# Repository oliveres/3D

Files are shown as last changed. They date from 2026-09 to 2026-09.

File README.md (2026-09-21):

# 3D models & browser tools

3D-printable models, editable CAD sources and browser configurators.

**[Open the tools website](https://oliveres.github.io/3D/)**

## Projects

| Project | Browser tool | Files and guide |
|---|---|---|
| DIN rail distribution stud — M6 / M8 / M10 | [Open configurator](https://oliveres.github.io/3D/din-rail/) | [Project folder](din-rail/) |
| DIN rail MEGA fuse holder — 2 × M8, 50.8 mm pitch | [Open configurator](https://oliveres.github.io/3D/mega-fuse/) | [Project folder](mega-fuse/) |

The DIN rail project provides a common-potential connection point for cable lugs, for example in Victron Energy systems. The separate MEGA fuse project mounts a fuse vertically across the rail on a compact 27 mm carrier. Both packages include printable STL files, STEP models, an OpenSCAD source, a Bambu Studio project and printing instructions.

Both projects use extended retaining lips and a U spring with 1.40 mm walls. The spring is thickened outwards by 0.20 mm, and its release-notch shoulder is removed. The inner spring opening, retaining-tip gap, rail registration faces and fuse carrier remain unchanged by this spring update.

## One Pages site, multiple tools

GitHub Pages publishes the root of the `main` branch. `.nojekyll` keeps the site as plain static files; no build system is needed.

Every tool has its own folder and `index.html`:

```text
index.html                  → https://oliveres.github.io/3D/
din-rail/index.html         → https://oliveres.github.io/3D/din-rail/
mega-fuse/index.html        → https://oliveres.github.io/3D/mega-fuse/
```

To add another tool:

1. Create a folder such as `your-next-tool/` with an `index.html` and any required assets.
2. Use relative links for local assets and downloads, so the tool works under `/3D/`.
3. Add a link or card to the root `index.html` and a row to the project table above.
4. Commit and push to `main`. GitHub Pages publishes the updated site automatically.

The new folder URL works once deployment finishes; the card on the home page is added manually. Files with other names also work at their full path, such as `your-next-tool/configurator.html`.

See [GitHub's Pages publishing documentation](https://docs.github.com/en/pages/getting-started-with-github-pages/configuring-a-publishing-source-for-your-github-pages-site).

## Credits and licensing

See each project's credits and any licence supplied with it. See the [distribution stud credits](din-rail/CREDITS.md) and [MEGA fuse holder credits](mega-fuse/CREDITS.md). No distribution licence for these new projects has been selected yet; credits to reference designs are included.

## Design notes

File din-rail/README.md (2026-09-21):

# DIN Rail Distribution Stud Holder

This is a **distribution stud for cable lugs**: a common-potential connection point for joining incoming and outgoing cables and distributing power, for example in **Victron Energy systems**. Cable lugs are stacked on the metal bolt and clamped with a nut. The printed holder secures that stud to the DIN rail.

A one-piece holder that clips onto a nominal 35 mm DIN rail and holds a hex-head bolt perpendicular to the rail. The head inserts from the rear into a captive hex recess; the threaded shank points outwards. One rail hook is fixed and the opposite latch uses a U-shaped spring with a screwdriver release notch.

[Open the live configurator](https://oliveres.github.io/3D/din-rail/) · [Download the complete offline package](DIN_Rail_Bolt_Holder_MakerWorld_Package.zip)

## Quick start

Open **index.html** in a desktop browser. It works offline and needs no installation. Select the four settings, preview the part and download an STL.

Alternatively, choose an STL from the `STL` folder, or open **DIN_Rail_Bolt_Holder.scad** in OpenSCAD, use its Customizer, press **F6**, then **File → Export → Export as STL**.

For Bambu Studio, `BambuStudio/DIN_M8_2module_36mm_X1C_PLA.3mf` contains the default M8 holder and suggested X1 Carbon / 0.4 mm nozzle / Generic PLA settings. Check the selected printer, filament and build plate before slicing. The editable project includes a sliced preview. Select your own printer, material and plate settings and slice again before printing.

## Four settings

| Setting | Choices / range | Default |
|---|---|---|
| Hex-head bolt | M6, M8, M10 with 16 mm head, M10 with 17 mm head | M8, 13 mm head |
| Holder width | M6/M8: 18 or 36 mm; M10: 27 or 36 mm | 36 mm |
| Rail width allowance | −0.50 to +0.50 mm relative to the 35.75 mm stop spacing | 0.00 mm |
| DIN rail sheet thickness | 0.80 to 2.00 mm | 1.00 mm |

One module is defined as **18 mm** in this model. The 27 mm option is 1.5 modules. The browser offers only compatible widths; OpenSCAD rejects invalid combinations.

### Default dimensions

- Nominal DIN rail width: **35 mm**.
- Distance between the rail registration faces: **35.75 mm**.
- U spring wall: **1.40 mm**; outer radius: **3.00 mm**.
- Distance between the retaining tips: **31.80 mm** (each lip extended inward by 0.50 mm).
- Rail sheet thickness: **1.00 mm**; both flange grooves: **1.20 mm**.
- Clearance between the body support and spring latch: **0.40 mm**, maintained across the sheet-thickness range.
- M8 holder width along the rail: **36 mm**.
- Default overall mounted envelope: **36 × 50 × 14.2 mm**.
- M8 through-hole: **8.60 mm**; hex recess: **13.35 mm across flats**, **6.80 mm deep**.

The width allowance changes the total stop spacing, split equally between both ends. For example, **+0.10 mm** gives **35.85 mm** stop spacing; each end moves outwards by 0.05 mm. A negative value narrows the gap. This is an adjustment to the model, not a measurement of the rail itself.

| Bolt | Head across flats | Through-hole | Hex recess across flats | Recess depth |
|---|---:|---:|---:|---:|
| M6 | 10 mm | 6.60 mm | 10.35 mm | 5.50 mm |
| M8 | 13 mm | 8.60 mm | 13.35 mm | 6.80 mm |
| M10 ISO | 16 mm | 10.60 mm | 16.35 mm | 8.00 mm |
| M10 DIN | 17 mm | 10.60 mm | 17.35 mm | 8.00 mm |

All eight supplied STL/STEP variants use **0.00 mm allowance** and **1.00 mm sheet thickness**. Bolt length is left to the application. Bolts, washers, nuts and DIN rail are not included.

## Printing

The STL exports are already lying on their side. Keep this orientation: it places spring bending in the layer plane. The STEP models use the mounted coordinate system and must be oriented before printing.

Suggested starting settings, also included in the Bambu Studio project:

- 0.4 mm nozzle, 0.20 mm layer height.
- Arachne wall generator, 6 walls, 6 top and bottom layers.
- 60% gyroid infill.
- Supports off; optional 4 mm outer brim.
- Remove any brim strands from the spring gap before fitting.

The clip design was developed through physical fit trials in PLA. The modular widths and custom parameter combinations need their own fit check; holder width and material affect spring stiffness. PLA, PETG and ASA require material-specific printing settings. The included project uses Generic PLA.

## Assembly and release

1. Clear the through-hole, hex recess and spring gap of stray filament.
2. Insert the bolt from the rear until its head sits in the hex recess.
3. Hook the fixed side over one DIN rail flange, then press the spring side over the opposite flange.
4. Place the cable lugs for the same electrical potential onto the exposed bolt and secure the connection with the appropriate nut and washers.
5. To remove the holder, use the notch beside the moving jaw to gently deflect the latch away from the rail, then lift that side free.

This is a mechanical holder. It does not establish an electrical current rating or a certified insulation rating for a cable connection.

## Package contents

- `index.html` — self-contained English browser configurator and STL exporter.
- `DIN_Rail_Bolt_Holder.scad` — self-contained English OpenSCAD source with four Customizer inputs.
- `STL/` — eight ready-to-slice variants, in print orientation.
- `STEP/` — matching eight solid CAD models, in mounted orientation.
- `BambuStudio/` — default M8 / 36 mm editable project with suggested settings.
- `images/` — two labelled CAD renders and a dimension diagram.
- `publishing/` — English MakerWorld listing text and upload notes for the author.
- `CREDITS.md` — design inspiration and dimensional references.
- `variants.json` — dimensions and parameters of each supplied variant.
- `CHECKSUMS.sha256` — file integrity hashes.

Digital validation covered 72 parameter combinations and comparison of 16 OpenSCAD/browser export pairs. All those meshes are closed, single solids. The support-to-latch gap was checked in every export. This does not replace a physical fit or load test of a chosen variant.

## Retention update

Both retaining lips were extended 0.50 mm towards the centre, including their insertion chamfers. This reduces the tip gap by 1.00 mm while preserving the rail registration faces, groove thickness, spring profile and bolt pocket. At +0.05 mm rail allowance, the tip gap is 31.85 mm; at the default 0.00 mm allowance it is 31.80 mm. The longer lips address reported accidental release; this revision still needs its own physical fit check.

## Spring update

The U spring is thickened by 0.20 mm along its outside, increasing its nominal wall from 1.20 to 1.40 mm. The moving leg and release-notch wall meet without the former 0.10 mm shoulder. The inside of the U, retaining tips, rail fit and bolt recess stay unchanged. This adjustment follows print feedback that the previous spring released too easily; fitting and release force still need to be checked on the actual print.

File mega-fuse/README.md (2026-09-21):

# DIN rail MEGA fuse holder

A compact, two-part holder for mounting a MEGA fuse vertically across a 35 mm DIN rail, for example in Victron Energy systems. Two M8 bolts have a fixed 50.8 mm centre spacing. Cable lugs attach at the two separate fuse terminals.

The current package combines **DIN clip v5** with the accepted **fuse carrier v3**. The U spring is thickened by 0.20 mm on the outside, increasing its nominal wall from 1.20 to 1.40 mm and removing the small shoulder at the release notch. The previously extended retaining tips remain unchanged. The carrier is unchanged. One hook stays fixed and the opposite hook releases through a U-shaped spring and screwdriver notch.

[Open the live configurator](https://oliveres.github.io/3D/mega-fuse/) · [Download the complete offline package](MEGA_Fuse_Holder_Package.zip)

## Quick start

Open `index.html` in a browser to preview the assembly, inspect the profile or exploded view, adjust rail fit and download STL files. Everything works offline. The package also includes editable OpenSCAD and STEP models and a Bambu Studio project.

## Dimensions

| Feature | Default |
|---|---:|
| Width along rail | 27 mm / 1.5 modules |
| Height across rail | 72.8 mm |
| Assembly depth, excluding hardware | 25.2 mm |
| M8 bolt pitch | 50.8 mm |
| M8 clearance holes | 8.6 mm |
| M8 hex-head pockets | 13.35 mm across flats × 6.3 mm deep |
| Matching clip/carrier contact footprint | 27 × 22 mm |
| Central recess below the terminal pads | 7.4 mm |
| Minimum free depth over the 29.2 × 19 mm fuse footprint, including chamfers | 6.1 mm |
| Rail registration spacing | 35.75 mm |
| Gap between retaining tips | 31.80 mm |
| Rail sheet thickness / flange grooves | 1.00 / 1.20 mm |
| Support-to-latch gap | 0.40 mm |
| U spring wall / outer radius | 1.40 / 3.00 mm |
| Static clearance above the spring arch | 0.80 mm |

The fuse footprint follows the supplied drawing: 68.8 mm overall length, 50.8 mm hole pitch, 8.7 mm holes, a 29.2 × 19 mm central body and 16.2 mm wide terminals. The drawing did not specify the side profile; check the actual body underside against the recess.

## Hardware and assembly

- Two M8 hex-head bolts with 13 mm heads; choose their length for the fuse and terminal stack.
- Two **M4 × 8 DIN 912 socket-head screws** and two plain M4 nuts, 7 mm across flats and nominally 3.2 mm thick.
- Suitable M8 nuts and washers for the actual terminal stack.

1. Insert the M8 bolts into the carrier from the rear, with their threads pointing outwards.
2. Insert the two M4 nuts into the rear pockets of the DIN clip.
3. Join the parts with the two M4 × 8 screws inserted through the central front recess. Their heads sit below its floor. Longer screws can protrude towards the rail.
4. Engage the fixed hook, then press the spring side onto the DIN rail. For removal, use the notch to move the spring latch outwards.
5. Mount the fuse and cable lugs with metal-to-metal contact. The two terminals remain separate except through the fuse.

This is a mechanical holder. It does not establish a current, thermal, fastening-torque or certified insulation rating for an electrical installation.

## Printing and rail fit

Both STL files are already oriented on their side, with a print height of 27 mm, so spring bending stays in the layer plane. Suggested starting settings are a 0.4 mm nozzle, 0.2 mm layers, Arachne, 6 walls, 60% gyroid infill and supports off. Clear any brim strands from the spring gap. The included Bambu project uses X1 Carbon and Generic PLA settings; select your actual printer, material and build plate, then slice again before printing. The project includes a sliced preview.

Rail allowance ranges from −0.50 to +0.50 mm. It changes the registration spacing of 35.75 mm and the retaining-tip gap of 31.80 mm by the same amount, shared equally between both ends. **At +0.05 mm allowance, the tip gap is 31.85 mm.** Sheet thickness ranges from 0.80 to 2.00 mm; each groove adds 0.20 mm clearance. The M8 pitch and carrier stay fixed.

The previous clip and carrier were refined from user feedback. The thicker spring is a new retention change and needs a fit check on the actual rail; narrower/wider allowances and material changes affect fitting and release force.

## Files

- `STL/MEGA_M8_clip_27mm_v5.stl` — current DIN clip with a thicker U spring and extended lips.
- `STL/MEGA_M8_carrier_27mm_v3.stl` — unchanged fuse carrier; an existing v3 print can be reused.
- `STEP/` — both parts and their assembly in installed coordinates.
- `MEGA_Fuse_Holder.scad` — both parts with rail allowance and sheet-thickness parameters; select `clip`, `carrier`, `layout` or `assembly`, render with F6, then export STL.
- `BambuStudio/` — current two-part X1 Carbon project, prepared on its side.
- `images/` — current CAD renders and dimensioned profile.
- `dimensions.json`, `CHECKSUMS.sha256` — dimensions and file integrity hashes.
- `publishing/`, `CREDITS.md` — listing text and references.

Product names identify compatibility; this is an independent design without a Victron Energy endorsement.

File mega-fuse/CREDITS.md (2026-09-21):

# Credits and references

This MEGA fuse holder and its two-parameter rail-fit configurator were constructed for this project. No reference STL is distributed in this package. The spring-clip mechanism was inspired by these models:

- **DIN Rail Clip (side mount)** — Catatat / PlasticXYZ. https://www.printables.com/model/1753870-din-rail-clip-side-mount
- **Adjustable DIN Rail Clip (FreeCAD)** — kc2zgu / marauder156. https://www.printables.com/model/556742-adjustable-din-rail-clip-freecad

The reference models were identified during development as CC BY 4.0. Preserve these credits and source links when publishing. See https://creativecommons.org/licenses/by/4.0/ for that reference licence. This statement credits the inspirations; it does not select a distribution licence for the new package.

The rail-clip profile comes from the preceding distribution-stud project, refined using physical print feedback. The carrier was accepted during user refinement; this release keeps it unchanged and thickens the outside of the U spring by 0.20 mm following further feedback about easy release. The thicker spring needs its own fit check. The assembly has two rear M8 head recesses at 50.8 mm pitch, a central body recess and two M4 attachment points. Rail width and sheet thickness are adjustable. CAD and configurator development used AI assistance.

Dimensional references:

- User-supplied MEGA fuse drawing: 50.8 mm pitch, 68.8 mm length, 29.2 × 19 mm central body footprint, 16.2 mm tabs and 8.7 mm holes.
- Victron fuse datasheet: https://www.victronenergy.com/upload/documents/Datasheet-Midi,-Mega-and-ANL-fuses,-and-fuse-holders-EN-.pdf

- Böllhoff DIN 933 hex-head screw dimensions: https://uk.misumi-ec.com/pdf/ds/AAU1/AAU1_DIN_933_Stahl_8_8_data_sheet_en1.pdf
- Würth, DIN / ISO hex-head differences: https://www.wuerth.de/web/de/awkg/kompetenz/din_iso_normteile/din-933-931-iso-4014-4017-sechskantschrauben.php/1000
- Schneider Electric, 18 mm module convention: https://www.se.com/in/en/faqs/FA600017/

Product names are used to identify compatibility or tooling, without an endorsement claim.

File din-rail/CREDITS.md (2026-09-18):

# Credits and references

The holder geometry and its four-parameter configurator were constructed for this project. No reference STL is distributed in this package. The spring-clip mechanism was inspired by these models:

- **DIN Rail Clip (side mount)** — Catatat / PlasticXYZ. https://www.printables.com/model/1753870-din-rail-clip-side-mount
- **Adjustable DIN Rail Clip (FreeCAD)** — kc2zgu / marauder156. https://www.printables.com/model/556742-adjustable-din-rail-clip-freecad

The reference models were identified during development as CC BY 4.0. Preserve these credits and source links when publishing. See https://creativecommons.org/licenses/by/4.0/ for that reference licence. This statement credits the inspirations; it does not select a distribution licence for the new package.

The new geometry adds a rear captive hex-head recess, a perpendicular bolt hole, selectable modular widths, symmetric rail-width adjustment and sheet-thickness adjustment with a constant support-to-latch gap. The design was iteratively refined using physical print feedback. CAD and configurator development used AI assistance.

Dimensional references:

- Böllhoff DIN 933 hex-head screw dimensions: https://uk.misumi-ec.com/pdf/ds/AAU1/AAU1_DIN_933_Stahl_8_8_data_sheet_en1.pdf
- Würth, DIN / ISO hex-head differences: https://www.wuerth.de/web/de/awkg/kompetenz/din_iso_normteile/din-933-931-iso-4014-4017-sechskantschrauben.php/1000
- Schneider Electric, 18 mm module convention: https://www.se.com/in/en/faqs/FA600017/

Product names are used to identify compatibility or tooling, without an endorsement claim.

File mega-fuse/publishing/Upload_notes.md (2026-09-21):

# Publishing notes

Use the current package only: DIN clip v5 and fuse carrier v3. The carrier STL is byte-for-byte identical to the accepted v3 model. Clip v5 thickens the U spring by 0.20 mm on the outside (1.40 mm walls), removes the release-notch shoulder and preserves the previously extended retaining tips.

Include the two STLs, the Bambu project if desired, and the ZIP containing the offline configurator and editable sources. The images are CAD renders, not photographs of a print. Check the current hook fit before describing it as physically verified. Preserve CREDITS.md and choose the distribution licence explicitly when publishing; no licence for the new design has been selected here.

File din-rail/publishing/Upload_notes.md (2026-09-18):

# MakerWorld upload notes — for the author

Suggested title: **DIN Rail Distribution Stud for Cable Lugs | M6 / M8 / M10**

Suggested tags: DIN rail, TS35, distribution stud, cable lugs, common potential, power distribution, Victron Energy, M6, M8, M10, parametric, OpenSCAD, electrical cabinet.

## Files and description

1. Use the eight files in `STL/` as model variants. Each is a complete single part, already in print orientation.
2. Add the OpenSCAD file as the editable parametric source. The HTML configurator and other supporting files can be distributed in a ZIP of this package. Check the current upload form for accepted attachment formats.
3. Paste the text from `MakerWorld_description.md` into the model description.
4. Add the CAD renders and dimension diagram as supplementary illustrations. They are labelled as renders.
5. Select the distribution licence in the upload form and add the corresponding licence file to the package when chosen. No licence grant for this new work has been chosen on the author's behalf. Preserve the linked design credits.
6. Disclose the AI-assisted development where the upload form asks for it.

## Bambu Studio project and photographs

The project in `BambuStudio/` is the default M8 / 36 mm part with suggested X1 Carbon / 0.4 mm / Generic PLA settings. It has been checked by local slicing, but this exact width/profile has not been confirmed by a physical print in this package.

Before submitting it as a tested print profile, print that configuration and add an actual photograph of its result. Add a photo of the mounted holder as well if available. CAD renders do not demonstrate a successful physical print.

Bambu Lab's guidance on actual print photographs and profiles:

- https://blog.bambulab.com/makerworld-in-20-days/
- https://wiki.bambulab.com/en/makerworld/tutorials/print-profile-upload

This folder contains prepared upload materials. No MakerWorld listing has been created or published.

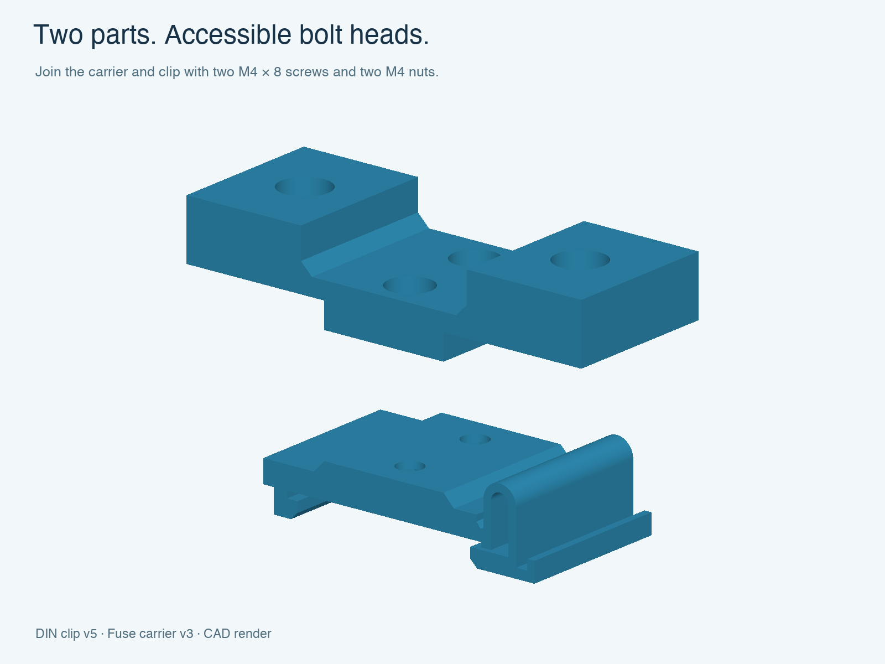
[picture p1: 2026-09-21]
mega-fuse/images/02_exploded.png

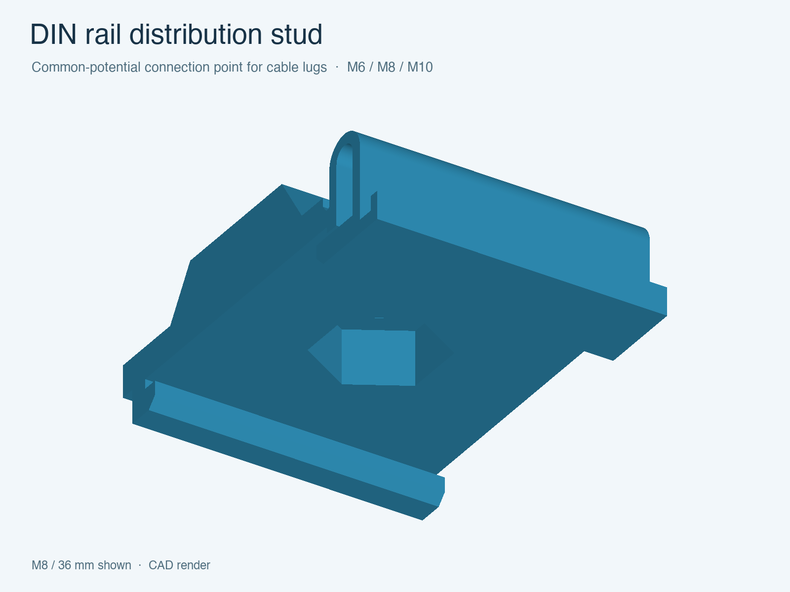
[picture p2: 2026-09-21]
din-rail/images/01_rear_CAD_render.png

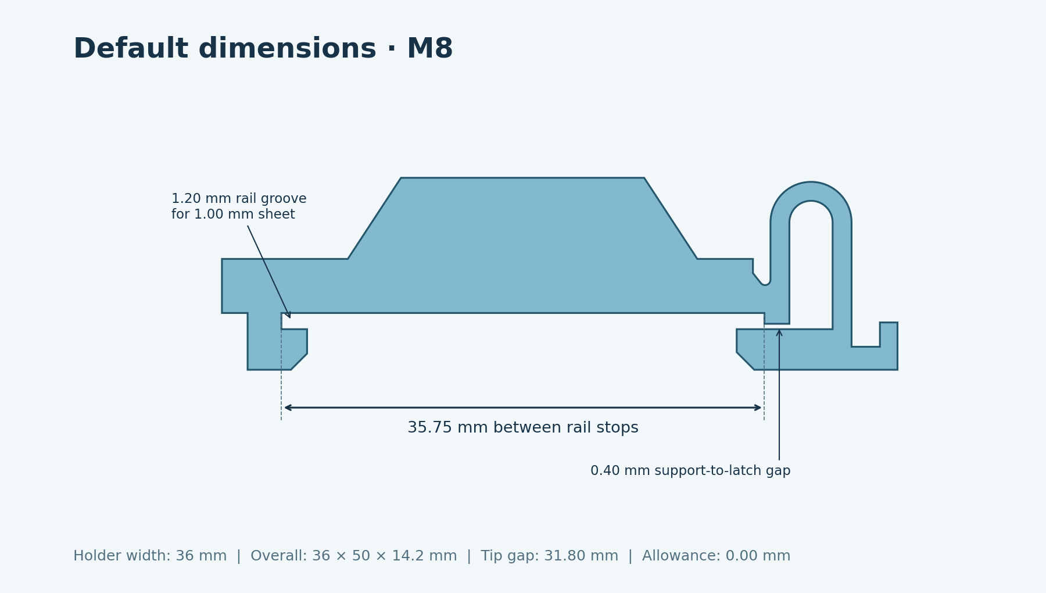
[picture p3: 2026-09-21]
din-rail/images/03_default_dimensions.png

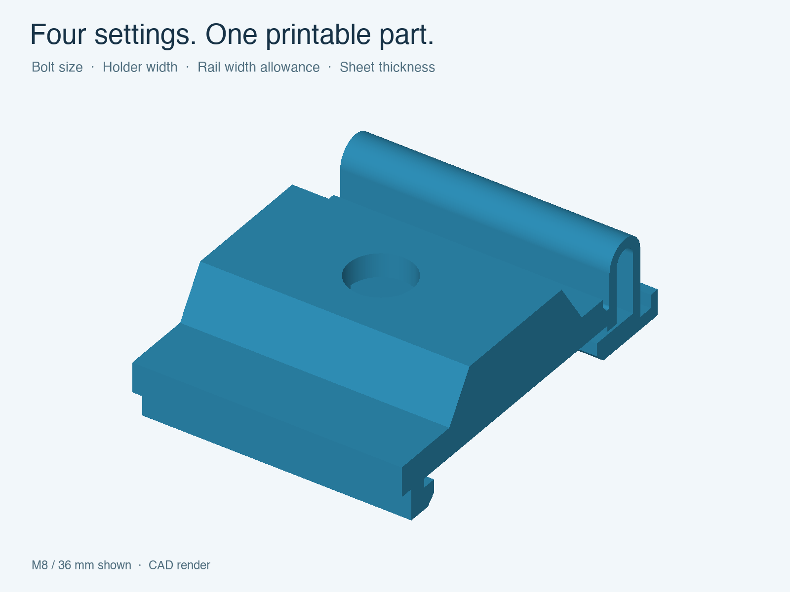
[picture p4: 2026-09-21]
din-rail/images/02_front_CAD_render.png

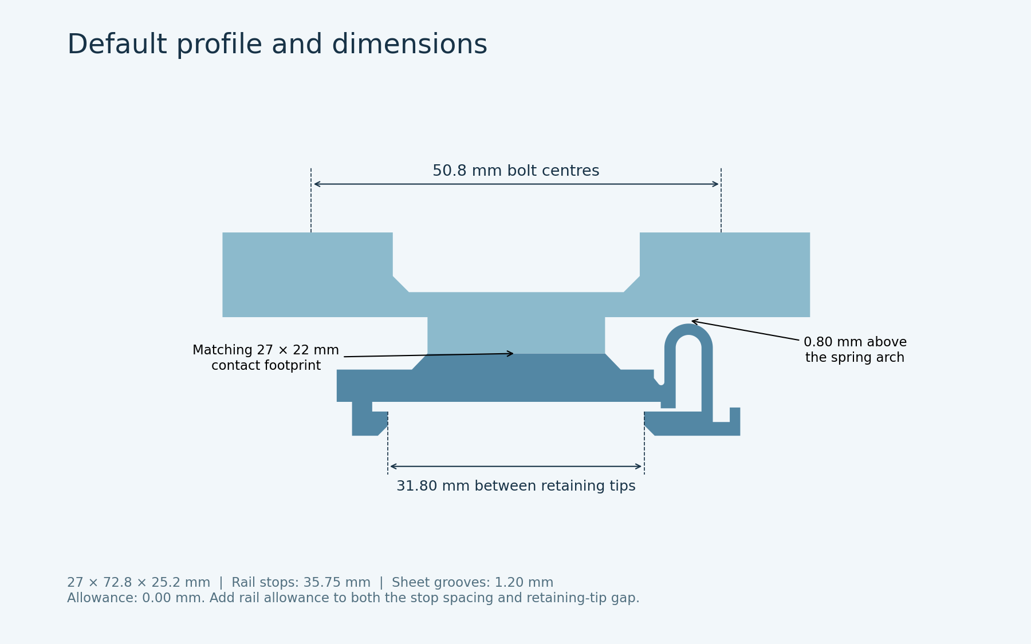
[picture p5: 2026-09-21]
mega-fuse/images/04_section.png

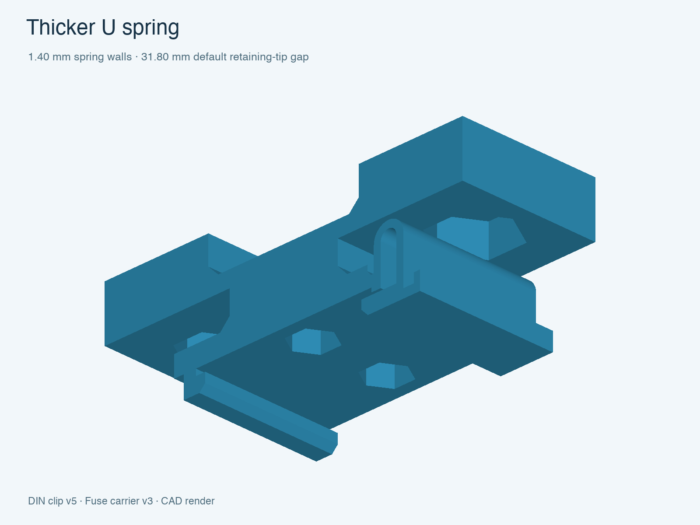
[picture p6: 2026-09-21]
mega-fuse/images/03_rear.png

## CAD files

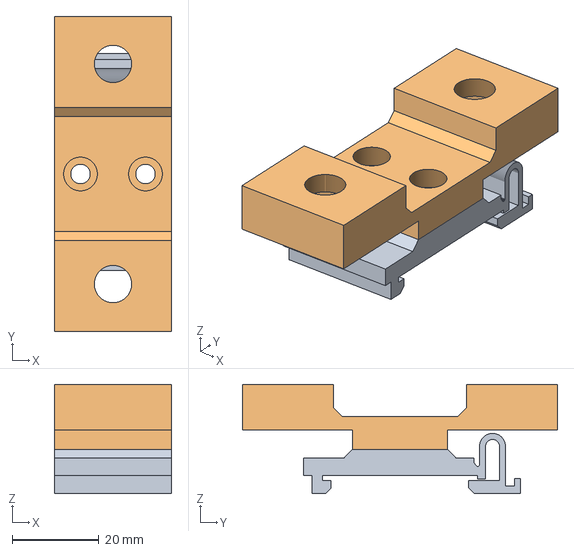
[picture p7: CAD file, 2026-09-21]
mega-fuse/STEP/MEGA_M8_assembly.step
27.0 x 72.8 x 25.2 mm
clip
carrier

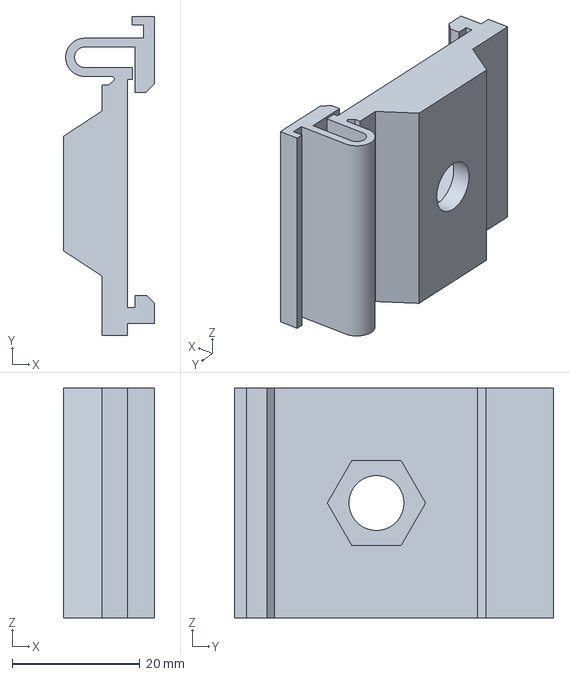
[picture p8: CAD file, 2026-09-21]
din-rail/BambuStudio/DIN_M8_2module_36mm_X1C_PLA.3mf
14.2 x 50.0 x 36.0 mm

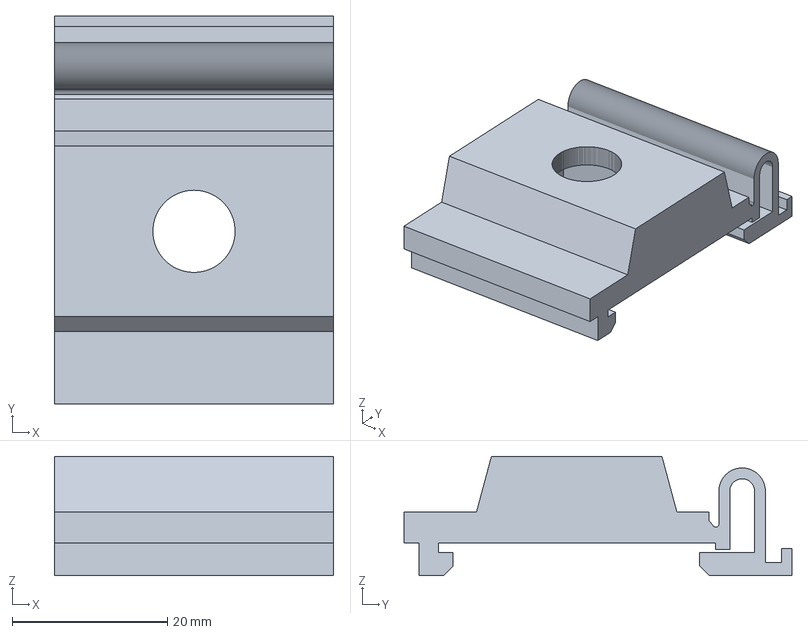
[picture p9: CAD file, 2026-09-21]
din-rail/STEP/DIN_M10_16_2module_36mm.step
36.0 x 50.0 x 15.4 mm

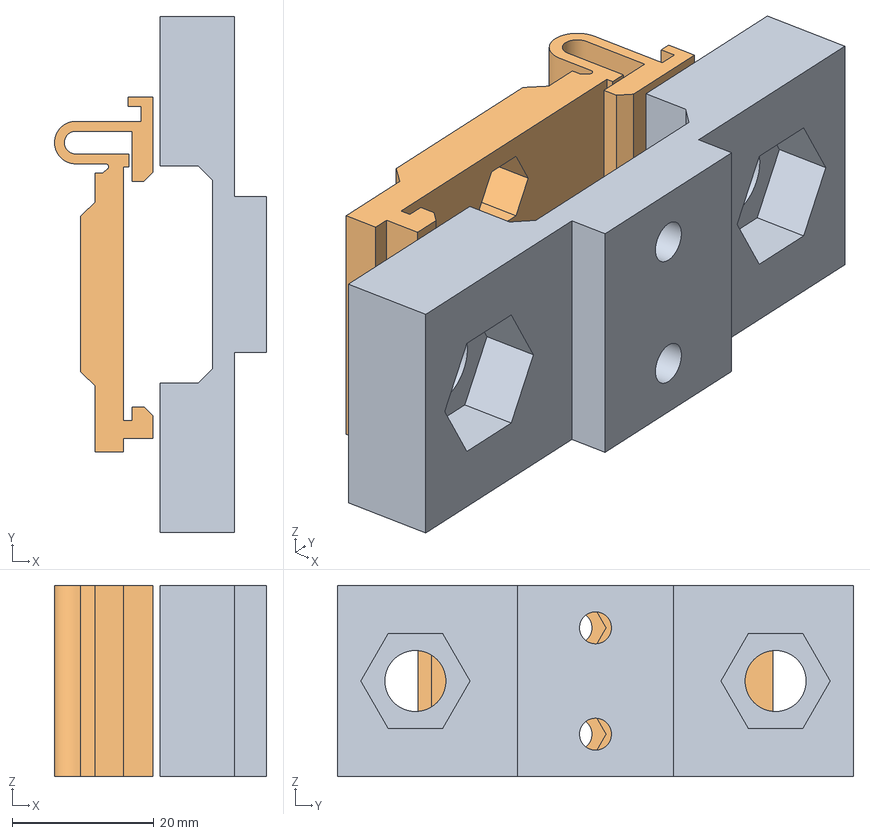
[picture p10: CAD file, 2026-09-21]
mega-fuse/BambuStudio/MEGA_M8_27mm_X1C_PLA.3mf
29.9 x 72.8 x 27.0 mm
MEGA_M8_carrier_27mm_v3.stl
MEGA_M8_clip_27mm_v5.stl

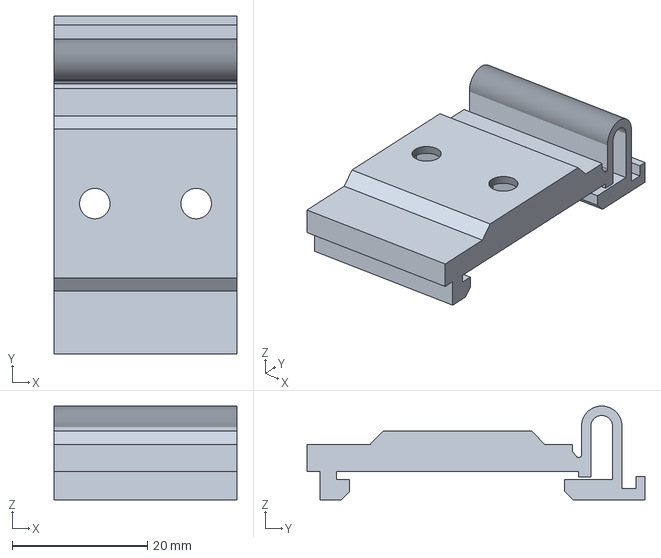
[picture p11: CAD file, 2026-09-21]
mega-fuse/STEP/MEGA_M8_clip_27mm_v5.step
27.0 x 50.0 x 13.9 mm

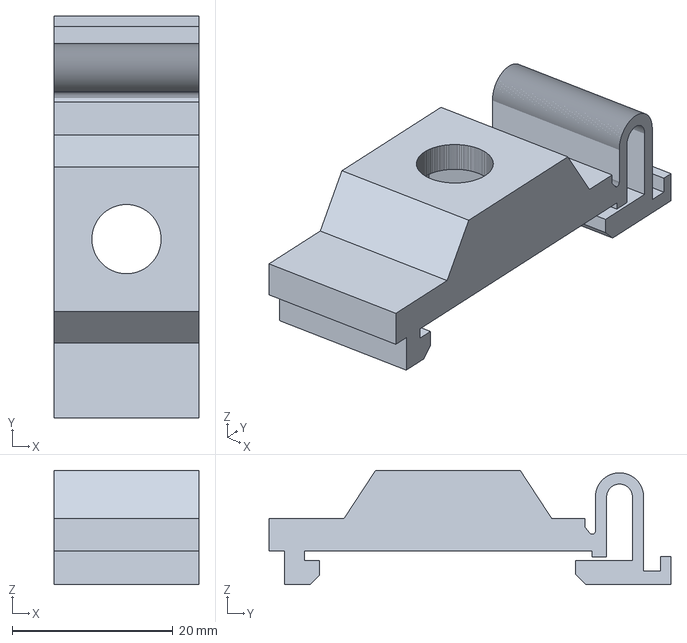
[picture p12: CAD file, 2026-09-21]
din-rail/STEP/DIN_M8_1module_18mm.step
18.0 x 50.0 x 14.2 mm

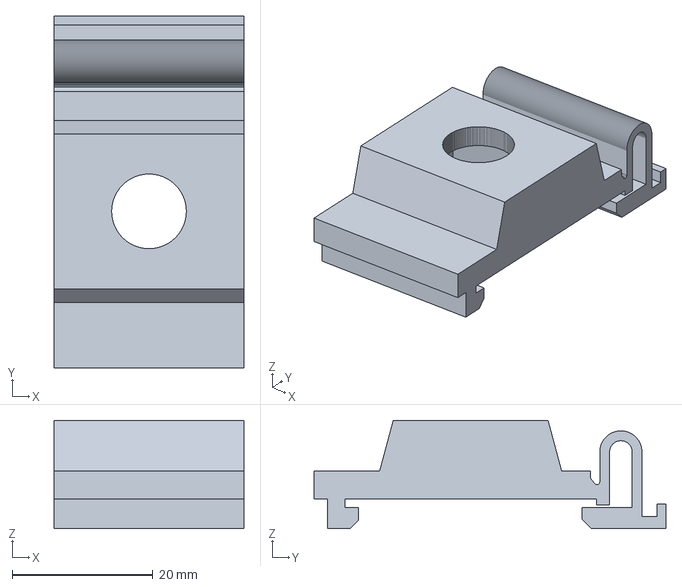
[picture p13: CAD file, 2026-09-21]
din-rail/STEP/DIN_M10_17_1p5module_27mm.step
27.0 x 50.0 x 15.4 mm

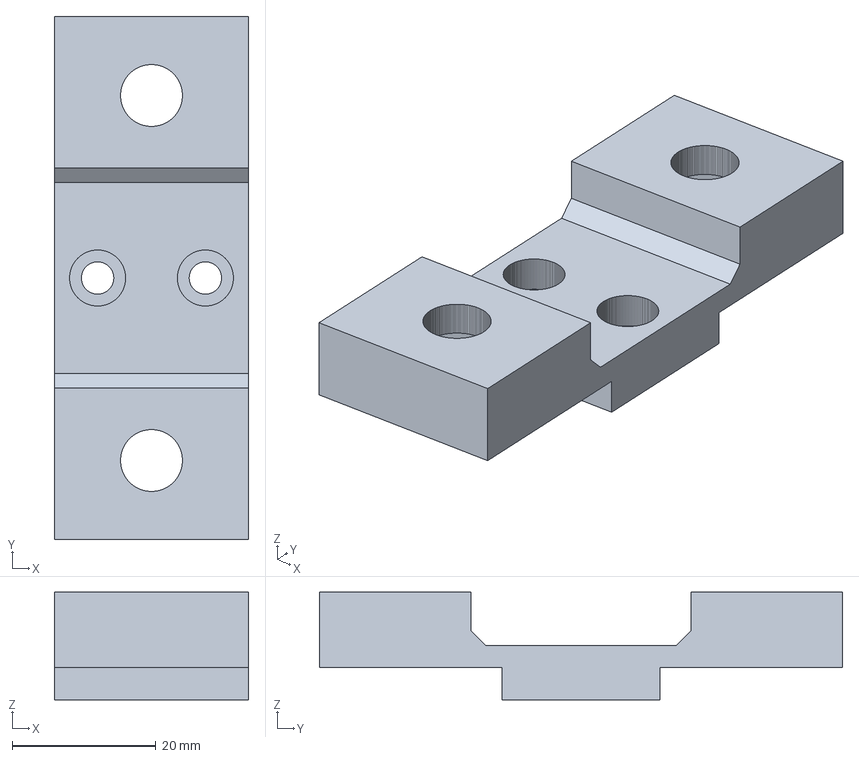
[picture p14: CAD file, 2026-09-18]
mega-fuse/STEP/MEGA_M8_carrier_27mm_v3.step
27.0 x 72.8 x 15.0 mm

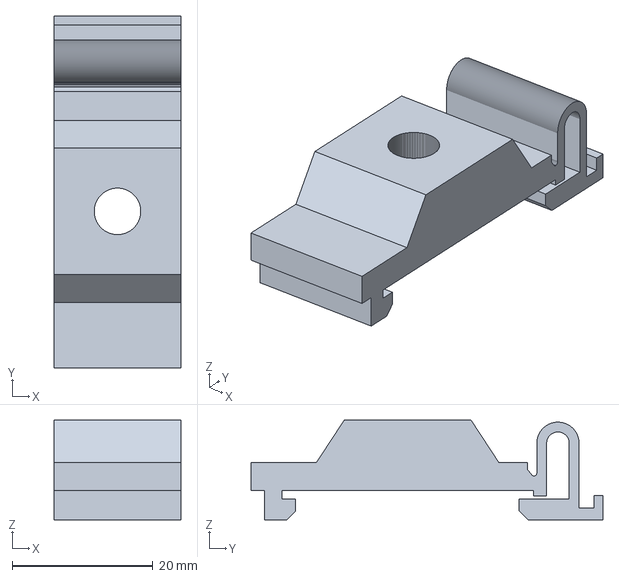
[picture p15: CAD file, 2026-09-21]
din-rail/STEP/DIN_M6_1module_18mm.step
18.0 x 50.0 x 14.2 mm

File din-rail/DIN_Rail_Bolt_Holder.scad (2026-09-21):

// DIN rail distribution stud holder — parametric model.
// Common-potential cable-lug connection point, e.g. for Victron Energy systems.
// The printed body mounts a metal distribution stud to a 35 mm DIN rail.
// Open in OpenSCAD, adjust the four Customizer inputs, press F6, Export > STL.
// Defaults: M8, 36 mm holder width, 35.75 mm stop spacing, 1 mm rail sheet.
// Retaining-tip gap at zero allowance: 31.80 mm. Both lips extend inward by 0.50 mm.
// U spring walls: 1.40 mm; outside thickened by 0.20 mm, release-notch shoulder removed.
// Each sheet groove includes 0.20 mm clearance. Support-to-latch gap: 0.40 mm.
// All exports are oriented for printing on their side, in millimetres.
// Wider or narrower holders change spring stiffness: check fit with a print.
// Clip mechanism inspiration (CC BY 4.0):
// Catatat / PlasticXYZ: https://www.printables.com/model/1753870-din-rail-clip-side-mount
// kc2zgu / marauder156: https://www.printables.com/model/556742-adjustable-din-rail-clip-freecad
// Bolt dimensions: https://uk.misumi-ec.com/pdf/ds/AAU1/AAU1_DIN_933_Stahl_8_8_data_sheet_en1.pdf

/* [Holder dimensions] */
// Bolt size and hex-head width across flats.
bolt = "M8"; // [M6:M6 - 10 mm head, M8:M8 - 13 mm head, M10_16:M10 - 16 mm head ISO, M10_17:M10 - 17 mm head DIN]
// M6/M8: 1 or 2 modules. M10: 1.5 or 2 modules. One module = 18 mm.
modules = 2; // [1:1 module - 18 mm, 1.5:1.5 modules - 27 mm, 2:2 modules - 36 mm]
// Added to the 35.75 mm default stop spacing. Split equally between both ends.
rail_allowance = 0; // [-0.5:0.05:0.5]
// Actual DIN rail sheet thickness. Groove clearance of 0.20 mm is added automatically.
sheet_thickness = 1; // [0.8:0.05:2]

/* [Hidden] */
$fn=128;
is_m10 = bolt=="M10_16" || bolt=="M10_17";
width = modules*18;
diameter = bolt=="M6" ? 6 : bolt=="M8" ? 8 : 10;
head_af = bolt=="M6" ? 10 : bolt=="M8" ? 13 : bolt=="M10_16" ? 16 : 17;
pocket_depth = bolt=="M6" ? 5.5 : bolt=="M8" ? 6.8 : 8;
front = is_m10 ? 11.2 : 10;
half_plateau = is_m10 ? 11 : 9;

// Side profile; curved sections are finely sampled for matching browser exports.
profile_points = [[12.93442623,4.0],[17.05,4.0],[17.05,2.945156212],[17.637652476,2.210590617],[17.682775991,2.162825679],[17.735110581,2.123092677],[17.793243991,2.092463807],[17.855607481,2.071765597],[17.920518166,2.061556589],[17.986224422,2.062112273],[18.050953157,2.073417657],[18.112957658,2.095167661],[18.170564725,2.126775361],[18.222219825,2.167387816],[18.266529037,2.215909096],[18.302296672,2.271029847],[18.328557535,2.331262627],[18.344602974,2.394982049],[18.35,2.460468636],[18.35,6.7],[18.351911523,6.807077002],[18.357643656,6.91401755],[18.367189095,7.020685364],[18.380535675,7.126944515],[18.397666387,7.232659589],[18.418559402,7.337695869],[18.443188095,7.441919502],[18.471521079,7.54519767],[18.50352225,7.647398762],[18.539150825,7.748392539],[18.578361402,7.848050297],[18.621104014,7.946245039],[18.66732419,8.04285163],[18.716963031,8.13774696],[18.769957279,8.2308101],[18.826239401,8.321922453],[18.885737675,8.41096791],[18.948376277,8.497832999],[19.014075385,8.582407022],[19.082751277,8.664582202],[19.154316434,8.744253819],[19.228679657,8.821320343],[19.305746181,8.895683566],[19.385417798,8.967248723],[19.467592978,9.035924615],[19.552167001,9.101623723],[19.63903209,9.164262325],[19.728077548,9.223760599],[19.8191899,9.280042721],[19.91225304,9.333036969],[20.00714837,9.38267581],[20.103754961,9.428895986],[20.201949703,9.471638598],[20.301607461,9.510849175],[20.402601237,9.54647775],[20.50480233,9.578478921],[20.608080498,9.606811905],[20.712304131,9.631440598],[20.817340411,9.652333613],[20.923055485,9.669464325],[21.029314636,9.682810905],[21.13598245,9.692356344],[21.242922998,9.698088477],[21.35,9.7],[21.457077002,9.698088477],[21.56401755,9.692356344],[21.670685364,9.682810905],[21.776944515,9.669464325],[21.882659589,9.652333613],[21.987695869,9.631440598],[22.091919502,9.606811905],[22.19519767,9.578478921],[22.297398762,9.54647775],[22.398392539,9.510849175],[22.498050298,9.471638598],[22.596245039,9.428895986],[22.69285163,9.38267581],[22.78774696,9.333036969],[22.8808101,9.280042721],[22.971922453,9.223760599],[23.06096791,9.164262325],[23.147832999,9.101623723],[23.232407022,9.035924615],[23.314582202,8.967248723],[23.394253819,8.895683566],[23.471320343,8.821320343],[23.545683566,8.744253819],[23.617248723,8.664582202],[23.685924615,8.582407022],[23.751623723,8.497832999],[23.814262325,8.41096791],[23.873760599,8.321922453],[23.930042721,8.2308101],[23.983036969,8.13774696],[24.03267581,8.04285163],[24.078895986,7.946245039],[24.121638598,7.848050297],[24.160849175,7.748392539],[24.19647775,7.647398762],[24.228478921,7.54519767],[24.256811905,7.441919502],[24.281440598,7.337695869],[24.302333613,7.232659589],[24.319464325,7.126944515],[24.332810905,7.020685364],[24.342356344,6.91401755],[24.348088477,6.807077002],[24.35,6.7],[24.35,-1.2],[24.35,-2.5],[26.45,-2.5],[26.45,-0.7],[27.75,-0.7],[27.75,-4.2],[17.15,-4.2],[15.85,-2.9],[15.85,-1.2],[22.95,-1.2],[22.95,6.7],[22.946965326,6.79849745],[22.937872815,6.896621265],[22.922756959,6.993999229],[22.901675098,7.090261952],[22.874707201,7.185044279],[22.841955567,7.277986666],[22.803544435,7.368736552],[22.759619511,7.456949691],[22.710347417,7.542291461],[22.65591506,7.62443813],[22.596528919,7.703078089],[22.532414268,7.77791303],[22.463814314,7.848659077],[22.39098928,7.915047867],[22.314215418,7.976827564],[22.233783957,8.033763816],[22.15,8.085640646],[22.063181369,8.132261266],[21.973657397,8.173448829],[21.881767679,8.209047095],[21.787860784,8.238921029],[21.692292933,8.262957308],[21.595426648,8.281064755],[21.497629375,8.293174682],[21.399272094,8.299241152],[21.300727906,8.299241152],[21.202370625,8.293174682],[21.104573352,8.281064755],[21.007707067,8.262957308],[20.912139216,8.238921029],[20.818232321,8.209047095],[20.726342603,8.173448829],[20.636818631,8.132261266],[20.55,8.085640646],[20.466216043,8.033763816],[20.385784582,7.976827564],[20.30901072,7.915047867],[20.236185686,7.848659077],[20.167585732,7.77791303],[20.103471081,7.703078089],[20.04408494,7.62443813],[19.989652583,7.542291461],[19.940380489,7.456949691],[19.896455565,7.368736552],[19.858044433,7.277986666],[19.825292799,7.185044279],[19.798324902,7.090261952],[19.777243041,6.993999229],[19.762127185,6.896621265],[19.753034674,6.79849745],[19.75,6.7],[19.75,-0.8],[17.9,-0.8],[17.9,0.0],[-17.85,0.0],[-17.85,-1.2],[-15.95,-1.2],[-15.95,-3.0],[-17.15,-4.2],[-20.35,-4.2],[-20.35,0.0],[-22.25,0.0],[-22.25,4.0],[-12.93442623,4.0],[-9.0,10.0],[9.0,10.0]]
;
// Extend the body stop with the moving jaw, retaining their 0.4 mm gap.
function sheet_z(y,z) = z-(sheet_thickness-1)*max(0,min(1,
    y>=17.9-0.000001 && y<=19.75+0.000001 ? -z/0.8 : (-z-0.8)/0.4));
function profile_point(p) = abs(p[1]-10)<0.000001
    ? [sign(p[0])*half_plateau,front]
    : [p[0]+(p[0]>14.5 ? rail_allowance/2 : p[0]<-14.5 ? -rail_allowance/2 : 0),sheet_z(p[0],p[1])];

assert(bolt=="M6" || bolt=="M8" || is_m10,"Invalid bolt size.");
assert(modules==2 || (is_m10 ? modules==1.5 : modules==1),
       "M6/M8 allows 1 or 2 modules; M10 allows 1.5 or 2 modules.");
assert(rail_allowance>=-0.5 && rail_allowance<=0.5,"Rail allowance must be between -0.5 and +0.5 mm.");
assert(sheet_thickness>=0.8 && sheet_thickness<=2,"Sheet thickness must be between 0.8 and 2 mm.");

module holder(){
    difference(){
        multmatrix([[0,0,1,0],[1,0,0,0],[0,1,0,0],[0,0,0,1]])
            linear_extrude(height=width,center=true,convexity=12)
                polygon([for(p=profile_points) profile_point(p)]);
        translate([0,0,-0.1]) linear_extrude(height=pocket_depth+0.1)
            polygon([for(a=[30:60:330]) [(head_af+0.35)/sqrt(3)*cos(a),(head_af+0.35)/sqrt(3)*sin(a)]]);
        translate([0,0,-0.1]) cylinder(d=diameter+0.6,h=front+0.2);
    }
}

// Orient the part on its side for printing; output units are millimetres.
translate([front,22.25+rail_allowance/2,width/2]) rotate([0,-90,0]) holder();
echo(width_mm=width,stop_spacing_mm=35.75+rail_allowance,sheet_groove_mm=sheet_thickness+0.2,retaining_tip_gap_mm=31.8+rail_allowance);

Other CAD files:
din-rail/STEP/DIN_M10_16_1p5module_27mm.step
din-rail/STEP/DIN_M8_2module_36mm.step
din-rail/STEP/DIN_M10_17_2module_36mm.step
din-rail/STEP/DIN_M6_2module_36mm.step
mega-fuse/MEGA_Fuse_Holder.scad
din-rail/STL/DIN_M10_16_1p5module_27mm.stl
din-rail/STL/DIN_M10_16_2module_36mm.stl
din-rail/STL/DIN_M10_17_1p5module_27mm.stl
din-rail/STL/DIN_M10_17_2module_36mm.stl
din-rail/STL/DIN_M6_1module_18mm.stl
din-rail/STL/DIN_M6_2module_36mm.stl
din-rail/STL/DIN_M8_1module_18mm.stl
din-rail/STL/DIN_M8_2module_36mm.stl
mega-fuse/STL/MEGA_M8_carrier_27mm_v3.stl
mega-fuse/STL/MEGA_M8_clip_27mm_v5.stl

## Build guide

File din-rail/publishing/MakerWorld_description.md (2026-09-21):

# DIN Rail Distribution Stud for Cable Lugs | M6 / M8 / M10

A **distribution stud for joining cable lugs at a common electrical potential**, for example in **Victron Energy systems**. Incoming and outgoing cable lugs are stacked on the bolt and secured with a nut, providing a shared connection point for power distribution. The printed holder mounts the metal stud to a DIN rail.

A one-piece holder for mounting a hex-head bolt on a **35 mm DIN rail**, with the threaded shank pointing outwards. The bolt head inserts from the rear into a recessed hex pocket. One hook stays fixed; the opposite side clips onto the rail using a U-shaped spring and releases through a screwdriver notch.

## Choose a ready-made size or customize your own

Eight STL variants are included:

| Bolt | Holder widths |
|---|---|
| M6, 10 mm head | 18 or 36 mm |
| M8, 13 mm head | 18 or 36 mm |
| M10 ISO, 16 mm head | 27 or 36 mm |
| M10 DIN, 17 mm head | 27 or 36 mm |

One module is 18 mm. M10 uses 1.5 or 2 modules to leave room around its larger head.

The downloadable package includes an **offline HTML configurator** with a 3D preview and STL export. Extract it and open the HTML file in your browser. No account, installation or internet connection is needed. An **OpenSCAD Customizer model** and **STEP files** are included too.

The four inputs are bolt size, holder width, DIN rail width allowance and rail sheet thickness.

## Default dimensions

**M8 · 36 mm wide · 35.75 mm between rail stops · 1.00 mm rail sheet · 1.20 mm flange grooves.**

Rail width allowance ranges from **−0.50 to +0.50 mm**, applied to the 35.75 mm stop spacing and shared equally between the two ends. Sheet thickness ranges from **0.80 to 2.00 mm**. Both grooves include 0.20 mm clearance; the gap between the body support and spring latch stays at 0.40 mm.

Both retaining lips extend 0.50 mm farther inward than in the initial release. Their default tip-to-tip gap is 31.80 mm; the rail registration spacing and sheet grooves stay the same.

## Printing and assembly

Use the supplied side-print orientation. Suggested starting settings: **0.4 mm nozzle, 0.20 mm layers, Arachne, 6 walls, 60% gyroid infill, supports off**. A 4 mm outer brim can help bed adhesion; clear the spring gap afterwards.

Insert the bolt from the rear, engage the fixed rail hook, then press the spring latch over the other flange. Bolt length, nuts and washers depend on the application. Use the release notch to move the latch away from the rail for removal.

The clip design was refined through physical fit trials in PLA. Different widths and materials change the spring stiffness, so check your selected variant with a print. The included Bambu Studio project is for **M8 / 36 mm, X1 Carbon, 0.4 mm nozzle and Generic PLA**. The modular variants have been digitally checked; this does not claim that every variant has been physically printed.

This is a mechanical holder, with no specified electrical current rating or certified insulation rating.

## Design credits

The spring-clip mechanism was inspired by [Catatat / PlasticXYZ](https://www.printables.com/model/1753870-din-rail-clip-side-mount) and [kc2zgu / marauder156](https://www.printables.com/model/556742-adjustable-din-rail-clip-freecad). The holder geometry and configurator were built for this project and refined from physical print feedback, with AI assistance. See CREDITS.md in the package.

The current U spring has 1.40 mm walls, thickened by 0.20 mm on the outside. Its inner opening and the retaining-tip gap are unchanged, and the release-notch shoulder is removed.

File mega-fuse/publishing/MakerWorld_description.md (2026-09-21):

# DIN Rail MEGA Fuse Holder | M8, 50.8 mm Pitch, 1.5 Modules

Mount a MEGA fuse vertically across a 35 mm DIN rail. This compact holder is 27 mm wide (1.5 modules), with two M8 studs at 50.8 mm centres for the fuse and cable lugs, for example in Victron Energy systems.

The removable carrier gives access to both rear hex-head pockets. Join it to the DIN clip with two M4 × 8 DIN 912 screws and two plain M4 nuts. The complete printed assembly measures 27 × 72.8 × 25.2 mm before adding hardware.

One DIN hook is fixed and the other uses a U-shaped spring with screwdriver release. This release extends both retaining lips 0.50 mm inward: the default retaining-tip gap is 31.80 mm, while the rail registration spacing stays 35.75 mm. The current pair is clip v5 and unchanged carrier v3.

An offline English browser tool previews the assembled and exploded parts, adjusts DIN rail allowance and sheet thickness, and exports print-oriented STL files. STEP models and an OpenSCAD source are included. M8 size, 50.8 mm pitch and 27 mm width stay fixed.

Print the parts on their supplied sides. Suggested starting settings: 0.4 mm nozzle, 0.20 mm layers, Arachne, 6 walls, 60% gyroid infill, supports off. The included Bambu Studio project is for X1 Carbon / Generic PLA. The extended hooks need a fit check on the actual rail.

Bolts, nuts, washers, fuse and cable lugs are not included. Choose M8 length to suit your terminal stack. This is a mechanical mount with no established electrical current, thermal or certified insulation rating.

See README.md for dimensions and assembly, and CREDITS.md for the rail-clip reference designs. Independent design; not an official Victron Energy product.

The U spring has 1.40 mm walls, thickened by 0.20 mm on the outside. The former release-notch shoulder is removed; retaining tips and rail fit are unchanged. Clearance above the arch is 0.80 mm.

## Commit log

2026-09-18 Add DIN rail distribution stud and GitHub Pages tools index
    [DIN_M10_16_1p5module_27mm.step, DIN_M10_16_1p5module_27mm.stl, DIN_M10_16_2module_36mm.step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]
2026-09-18 Extend DIN retaining hooks and add MEGA fuse holder
    [DIN_M10_16_1p5module_27mm.step, DIN_M10_16_1p5module_27mm.stl, DIN_M10_16_2module_36mm.step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]
2026-09-21 Thicken DIN U springs outward by 0.2 mm
    [DIN_M10_16_1p5module_27mm.step, DIN_M10_16_1p5module_27mm.stl, DIN_M10_16_2module_36mm.step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]
